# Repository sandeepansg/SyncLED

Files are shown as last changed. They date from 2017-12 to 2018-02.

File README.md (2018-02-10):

<h1 align="center"> SyncLED </h1> <br>
<p align="center">
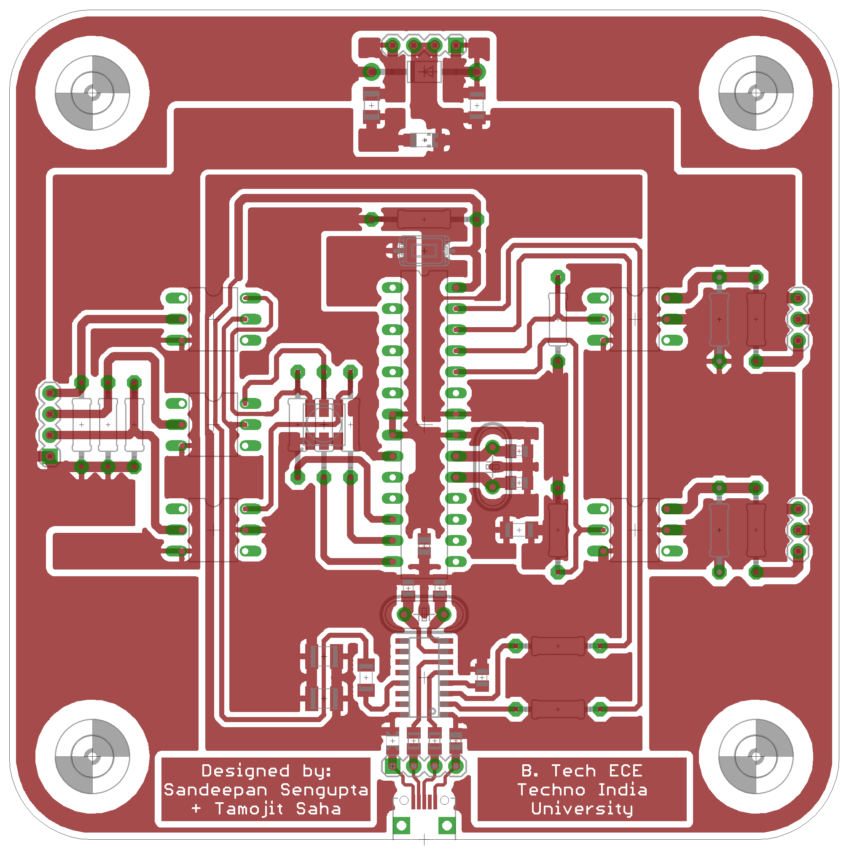
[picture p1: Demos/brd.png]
SyncLED Board Layout

</p>

## Table of Contents

- [Introduction](#introduction)
- [Features](#features)
- [Feedback](#feedback)
- [Contributors](#contributors)
- [License](#license)
- [Acknowledgments](#acknowledgments)

## Introduction






SyncLED is a implementation of a basic secure communication framework to bridge between a host software and a slave LED controller. The host software grabs the bus reported temperature data using [Open Hardware Monitor Library](https://github.com/SandeepanSengupta/SyncLED/blob/master/Sources/Application/Bridge/New/OpenHardwareMonitorLib.dll) and sends it over the usb to the salve embedded led controller using the self-tailored secure communication format.
<p align="center">
  <a href="https://gitpoint.co/">
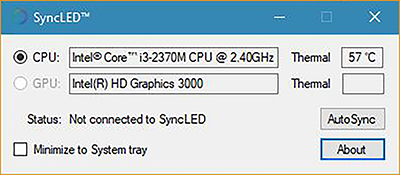
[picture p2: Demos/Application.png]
Windows_App Host Software
    
  </a>
</p>

<p align="center">
  Screenshot of host software.
</p>

## Features
- Real-time temperature monitoring of CPU and GPU
- Temperature dependent LED control
- Independent Host software

## Social
Connect us here:
<br><br>
 <br>
 
<p> 
or <a href ="https://github.com/TamojitSaha/LTC2633/issues/new/">file an issue</a>. Feature requests are always welcome.</p>

## License
Contents of this repository are realeased under [CC-BY-NC-SA 4.0](./LICENSE.md) <br>


## Acknowledgments

Thanks to [Google](https://www.google.com) and various developers for supporting us with a tons of developments... :wink:

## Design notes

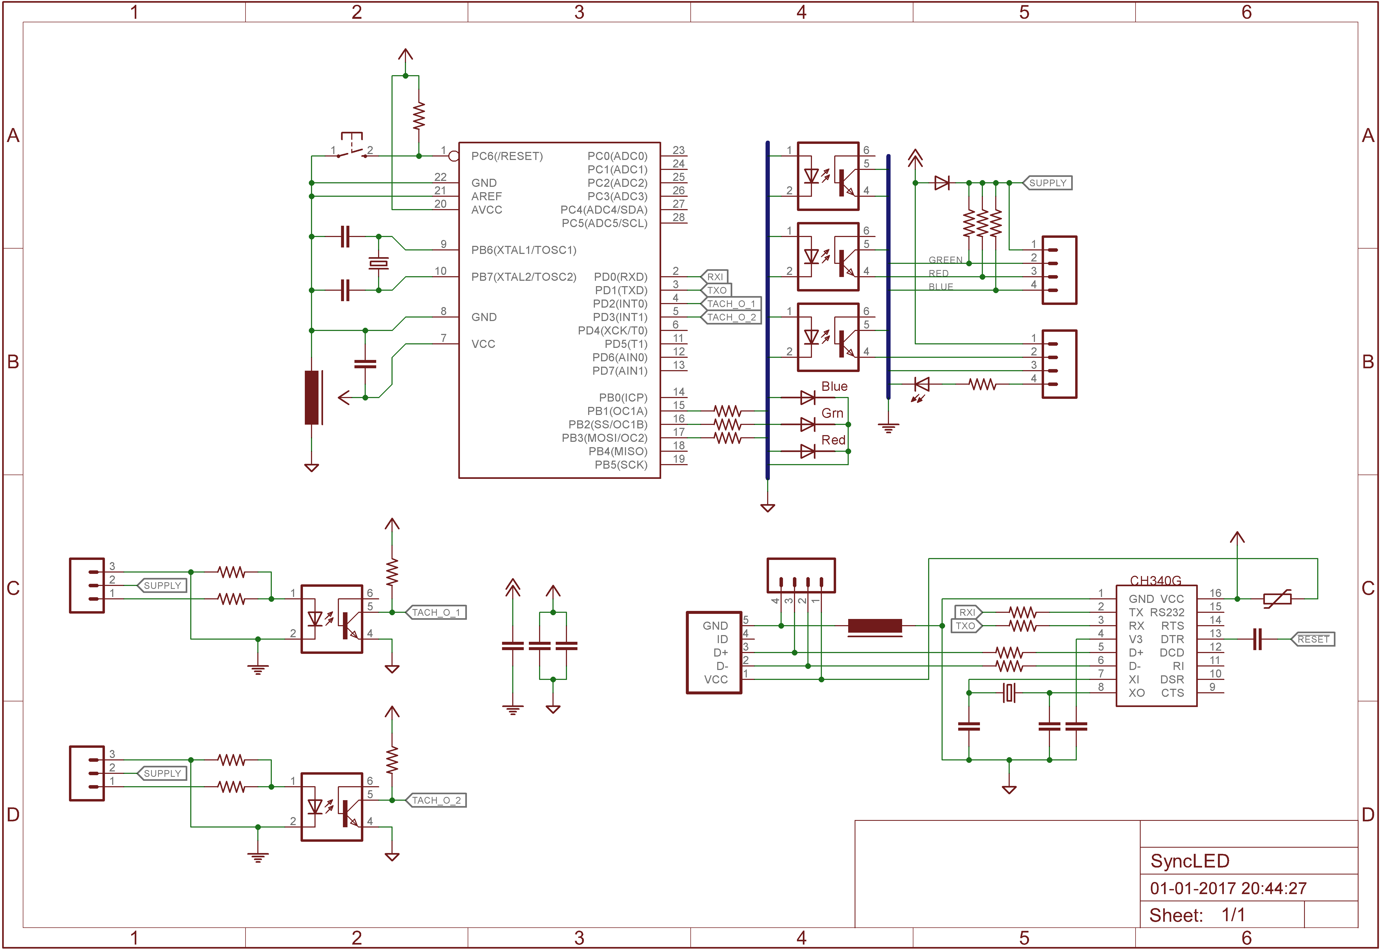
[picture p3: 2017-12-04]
Demos/sch.png

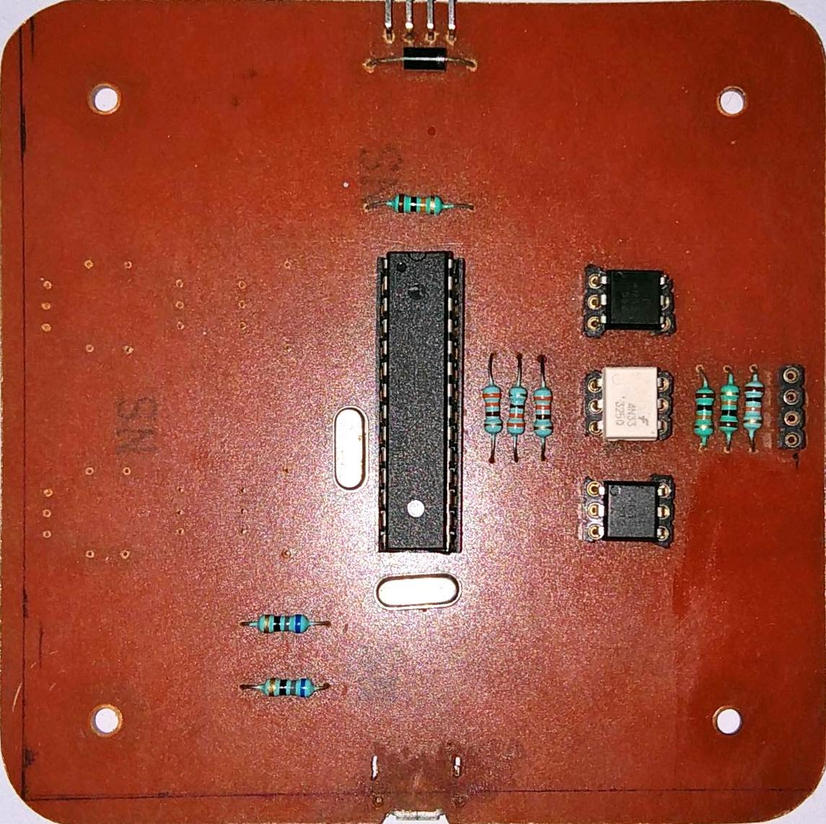
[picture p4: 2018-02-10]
Demos/Device.jpg

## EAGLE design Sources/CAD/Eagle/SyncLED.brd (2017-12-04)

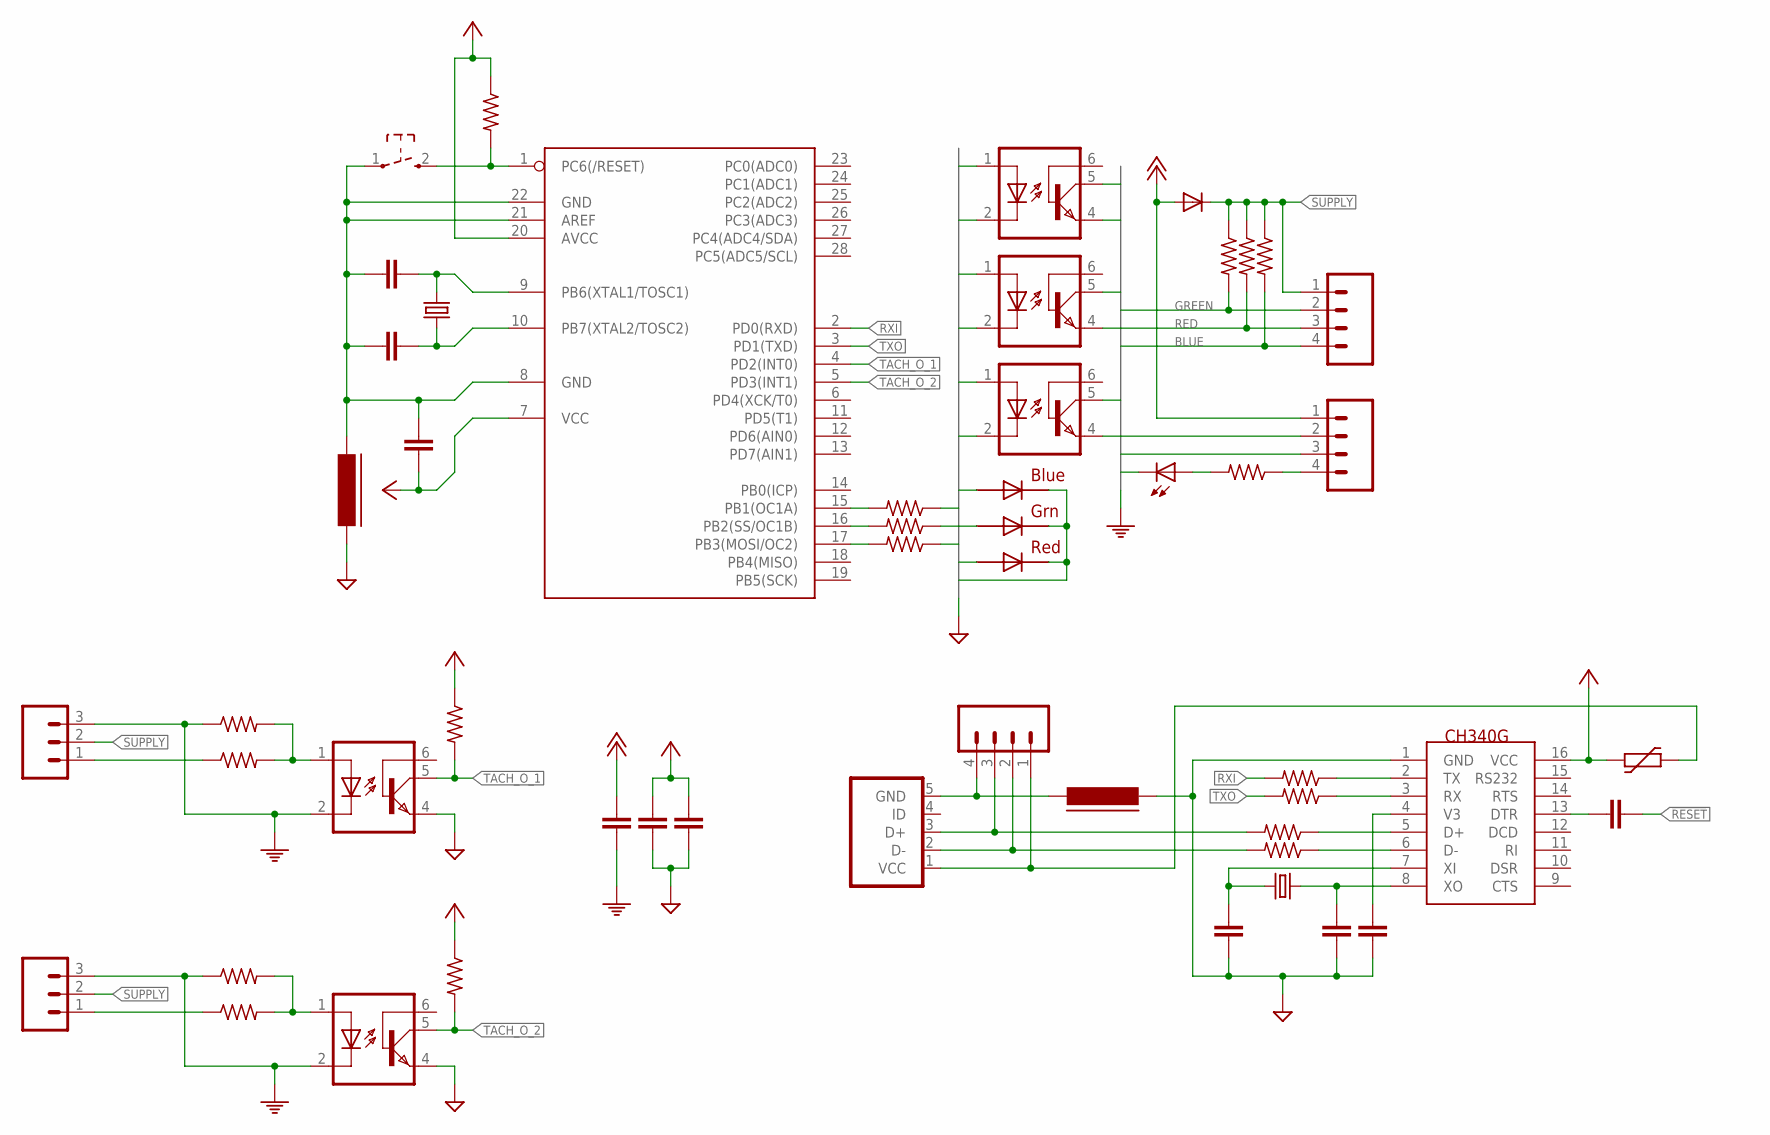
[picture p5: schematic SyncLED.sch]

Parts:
!RES: SMD; SW_TACT_3X6
C1, C2, C3, C4: 22pF; C0805K
CAP_!DTR: 100nF; C1206K
CAP_BYPASS: 22pF; C0805K
CAP_DIGITAL_1, CAP_DIGITAL_2: 1uF; C1210K
CAP_LED: 1uF; C1206K
CAP_MCU: 10uF; C1206K
DIODE_LED: 1N4004; DO41-10
FAN_HEADER_1, FAN_HEADER_2: M03PTH; 1X03
FERRITE_MCU: UGND; FB805
FERRITE_USB: UGND; FB805
INDICATOR: RGBLED5050
LED_OUTPUT: M04PTH; 1X04
MCU: MEGA8-P; DIL28-3
OPTO_BLUE: 4N35; DIL06
OPTO_GREEN: 4N35; DIL06
OPTO_RED: 4N35; DIL06
OPTO_TACH_1, OPTO_TACH_2: 4N35; DIL06
POWER_INDICATOR: LEDCHIPLED_1206; CHIPLED_1206
PPTC: 500mA; PTC0805
RES_BLUE: 10K; 0207/10
RES_B_IN: 100E; 0207/12
RES_D+: 100E; M0805
RES_D-: 100E; M0805
RES_GREEN: 10K; 0207/10
RES_G_IN: 100E; 0207/12
RES_LED: 10K; M1206
RES_PULLUP: 10K; 0207/12
RES_RED: 10K; 0207/10
RES_RX: 100E; 0207/10
RES_R_IN: 100E; 0207/12
RES_TACH_1, RES_TACH_2: 100E; 0207/10
RES_TACH_PULLDOWN_1, RES_TACH_PULLDOWN_2: 1K; 0207/10
RES_TACH_PULLUP_1, RES_TACH_PULLUP_2: 10K; 0207/10
RES_TX: 100E; 0207/10
SMPS_SUPPLY: M04PTH; 1X04
USB2UART: CH340G; SOIC16
USB-RECEPTABLE: USB-Micro; FCI-10103594-0001LF
USB_PORT: M04PTH; 1X04
XTAL_MCU: CRYSTALHC49S; HC49/S
XTAL_USB: CRYSTALHC49S; HC49/S

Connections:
3V: CAP_BYPASS.1, USB2UART.4 (V3)
!DTR: CAP_!DTR.1, USB2UART.13 (DTR)
!RESET: !RES.2 (3), CAP_!DTR.2, MCU.1 (PC6(/RESET)), RES_PULLUP.2
+5V: CAP_DIGITAL_1.1, CAP_DIGITAL_2.1, CAP_MCU.1, MCU.7 (VCC), MCU.20 (AVCC), PPTC.1, RES_PULLUP.1, RES_TACH_PULLUP_1.1, RES_TACH_PULLUP_2.1, USB2UART.16 (VCC)
+12V: CAP_LED.1, DIODE_LED.A, SMPS_SUPPLY.1
BLUE: LED_OUTPUT.4, OPTO_BLUE.5 (COL), RES_BLUE.2
B_IN: MCU.17 (PB3(MOSI/OC2)), RES_B_IN.2
B_OUT: INDICATOR.3 (BLUE_A), OPTO_BLUE.1 (A), RES_B_IN.1
DGND: C1.2, C2.2, CAP_BYPASS.2, CAP_DIGITAL_1.2, CAP_DIGITAL_2.2, FERRITE_MCU.1, FERRITE_USB.2, INDICATOR.4 (BLUE_C), INDICATOR.5 (RED_C), INDICATOR.6 (GREEN_C), OPTO_BLUE.2 (C), OPTO_GREEN.2 (C), OPTO_RED.2 (C), OPTO_TACH_1.4 (EMI), OPTO_TACH_2.4 (EMI), USB2UART.1 (GND)
DI_I: RES_D+.2, USB-RECEPTABLE.3 (D+), USB_PORT.3
DI_O: RES_D-.2, USB-RECEPTABLE.2 (D-), USB_PORT.2
DO_N: RES_D-.1, USB2UART.6 (D-)
DO_P: RES_D+.1, USB2UART.5 (D+)
GREEN: LED_OUTPUT.2, OPTO_GREEN.5 (COL), RES_RED.2
GROUND: CAP_LED.2, FAN_HEADER_1.3, FAN_HEADER_2.3, OPTO_BLUE.4 (EMI), OPTO_GREEN.4 (EMI), OPTO_RED.4 (EMI), OPTO_TACH_1.2 (C), OPTO_TACH_2.2 (C), POWER_INDICATOR.C, RES_TACH_PULLDOWN_1.1, RES_TACH_PULLDOWN_2.1, SMPS_SUPPLY.2, SMPS_SUPPLY.3
G_IN: MCU.16 (PB2(SS/OC1B)), RES_G_IN.2
G_OUT: INDICATOR.1 (GREEN_A), OPTO_GREEN.1 (A), RES_G_IN.1
LED_SUPPLY: POWER_INDICATOR.A, RES_LED.2
MCU_GND: !RES.1, C3.1, C4.1, CAP_MCU.2, FERRITE_MCU.2, MCU.8 (GND), MCU.21 (AREF), MCU.22 (GND)
MCU_XI: C3.2, MCU.9 (PB6(XTAL1/TOSC1)), XTAL_MCU.2
MCU_XO: C4.2, MCU.10 (PB7(XTAL2/TOSC2)), XTAL_MCU.1
RED: LED_OUTPUT.3, OPTO_RED.5 (COL), RES_GREEN.2
RXI: MCU.2 (PD0(RXD)), RES_TX.2
RXO: RES_RX.1, USB2UART.3 (RX)
R_IN: MCU.15 (PB1(OC1A)), RES_R_IN.2
R_OUT: INDICATOR.2 (RED_A), OPTO_RED.1 (A), RES_R_IN.1
SUPPLY: DIODE_LED.C, FAN_HEADER_1.2, FAN_HEADER_2.2, LED_OUTPUT.1, RES_BLUE.1, RES_GREEN.1, RES_RED.1
SUPPLY_5V: RES_LED.1, SMPS_SUPPLY.4
TACH_IN_1: FAN_HEADER_1.1, RES_TACH_1.1
TACH_IN_2: FAN_HEADER_2.1, RES_TACH_2.1
TACH_OPTO_1: OPTO_TACH_1.1 (A), RES_TACH_1.2, RES_TACH_PULLDOWN_1.2
TACH_OPTO_2: OPTO_TACH_2.1 (A), RES_TACH_2.2, RES_TACH_PULLDOWN_2.2
TACH_O_1: MCU.4 (PD2(INT0)), OPTO_TACH_1.5 (COL), RES_TACH_PULLUP_1.2
TACH_O_2: MCU.5 (PD3(INT1)), OPTO_TACH_2.5 (COL), RES_TACH_PULLUP_2.2
TXI: RES_TX.1, USB2UART.2 (TX)
TXO: MCU.3 (PD1(TXD)), RES_RX.2
USB_GND: FERRITE_USB.1, USB-RECEPTABLE.5 (GND), USB_PORT.4
USB_XI: C2.1, USB2UART.7 (XI), XTAL_USB.1
USB_XO: C1.1, USB2UART.8 (XO), XTAL_USB.2
VUSB: PPTC.2, USB-RECEPTABLE.1 (VCC), USB_PORT.1

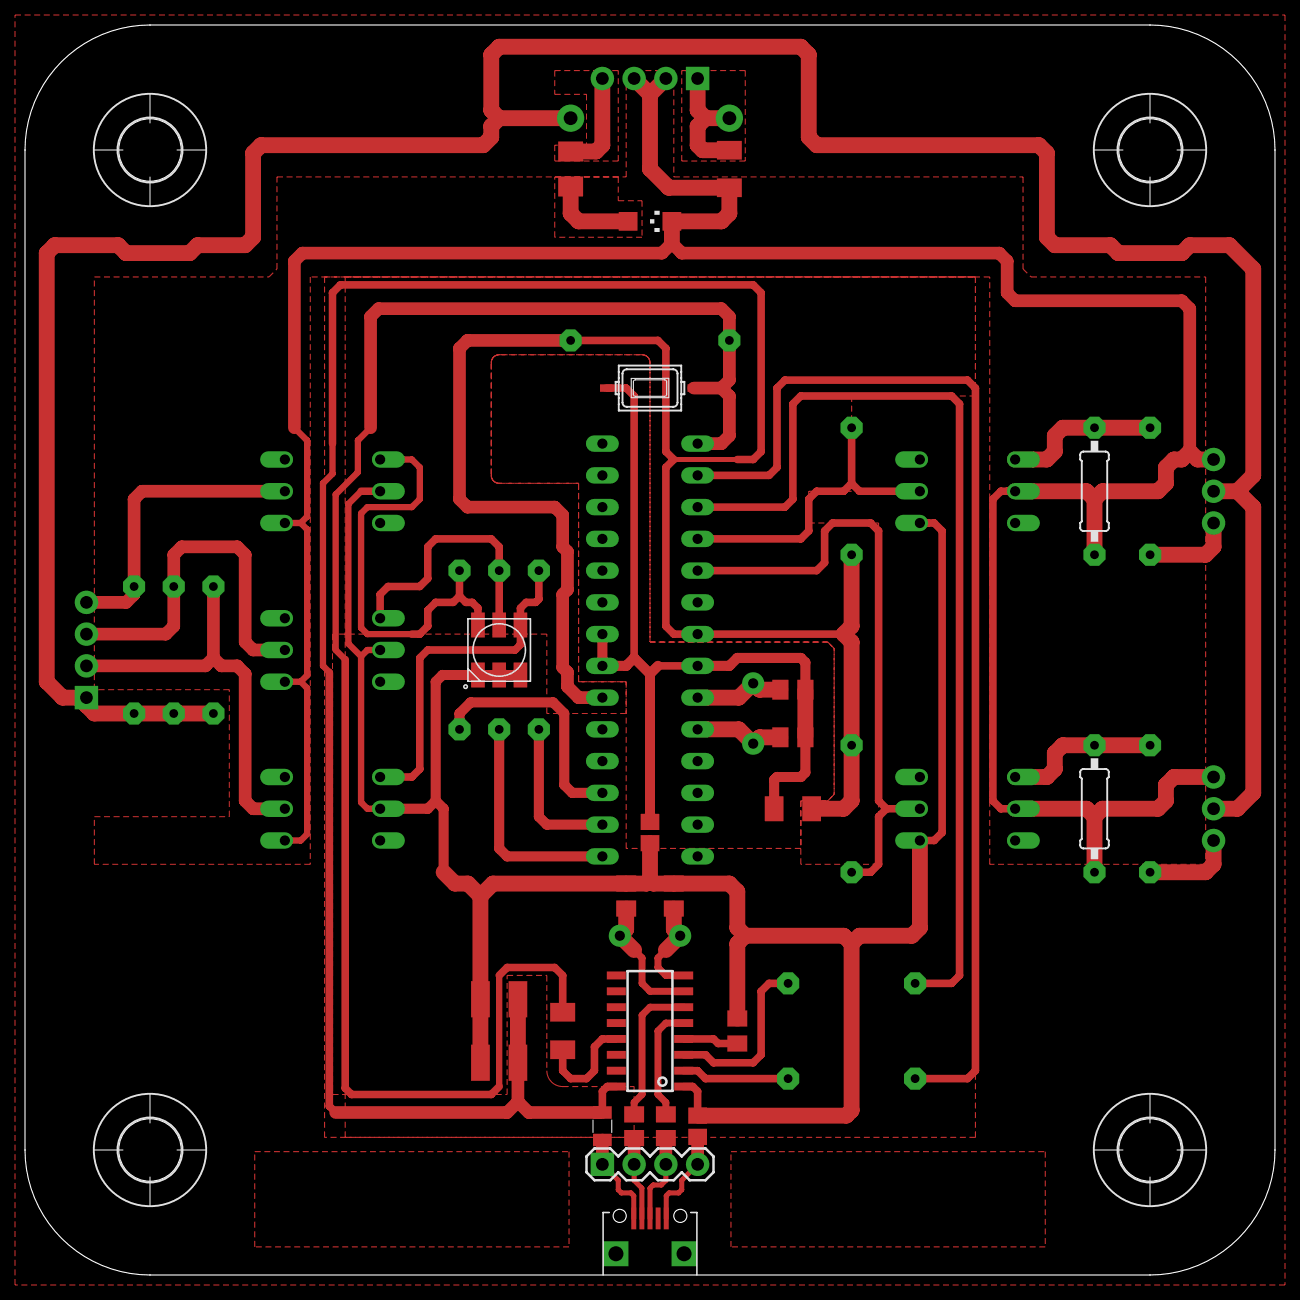
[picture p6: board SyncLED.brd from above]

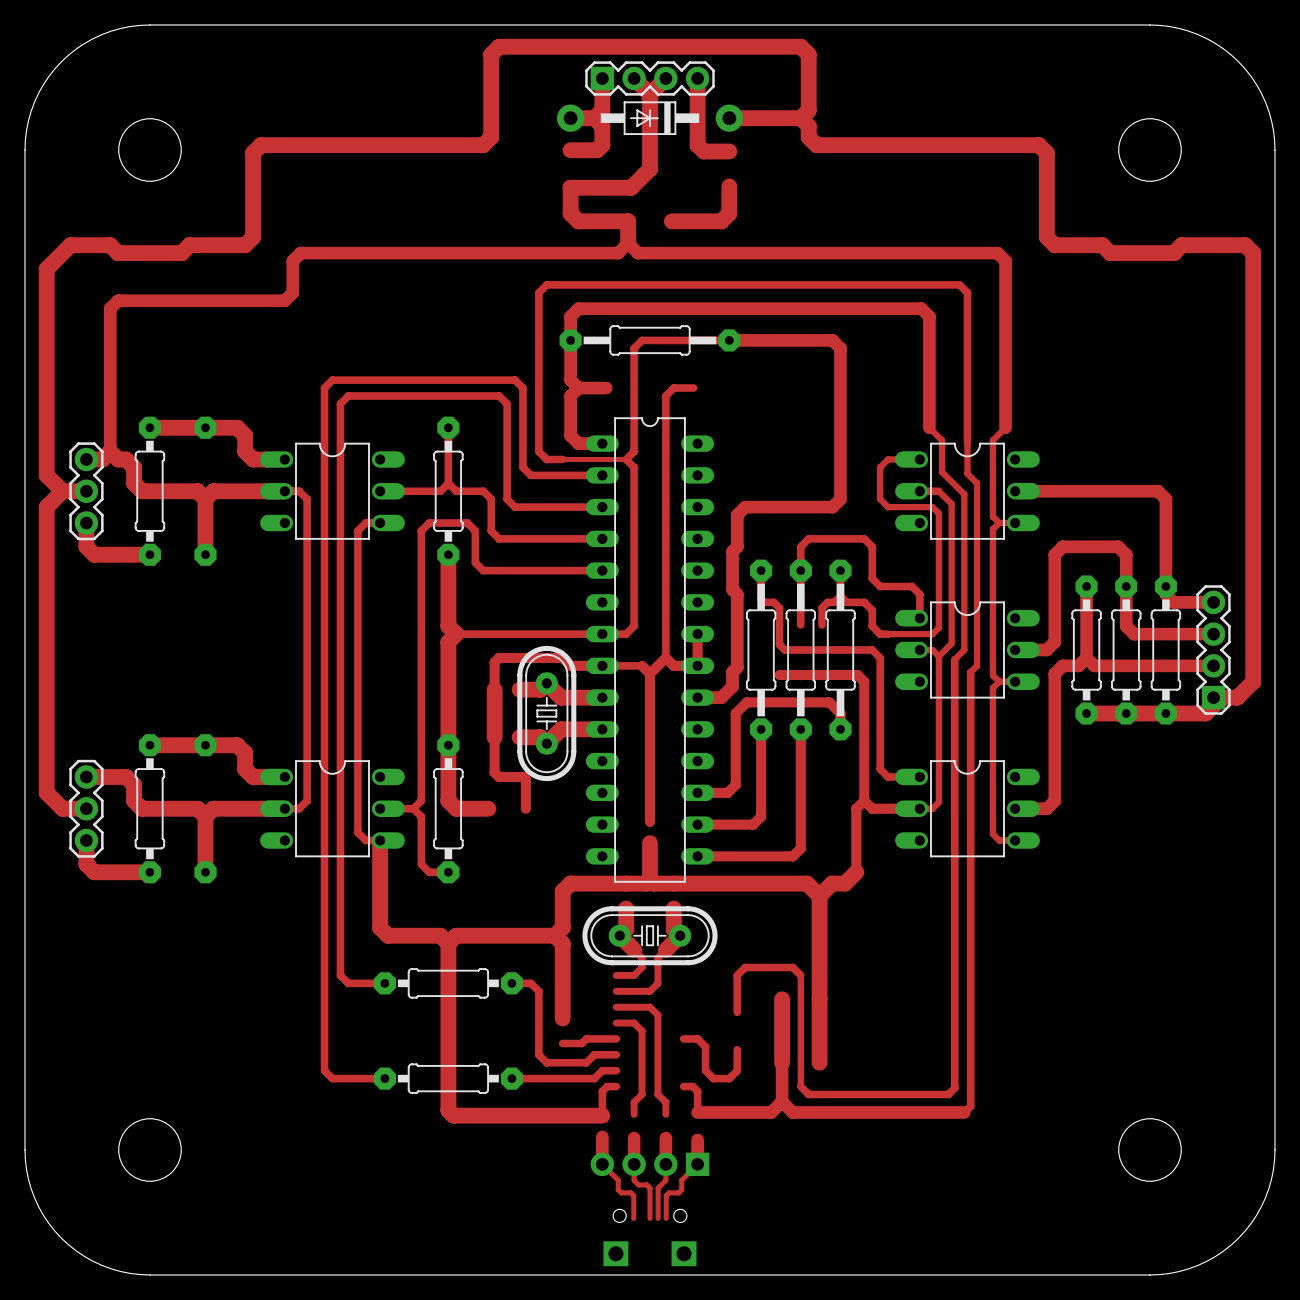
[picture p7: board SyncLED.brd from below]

Board: 2 copper layers, 100.0 x 100.0 mm, 54 parts (26 on the bottom side), 40 nets.

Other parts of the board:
U$1, U$2, U$3, U$5: 5,0

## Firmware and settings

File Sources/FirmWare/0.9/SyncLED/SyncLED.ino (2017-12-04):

/*
  Infineo Communication framework for SyncLED™ (Version 0.9)
  Author(s): Sandeepan Sengupta, Tamojit Saha

  Frame format:

  Inputs are 8 charectors in an UART stream
  Charector 1 is Identifier
  Charector 2~7 are Payload in HEX charectors
  Charector 8 is Termination Indicator

  Registered identifier(s): '~' , '!' , '@' , '#' and '*'
  Registered termination indicator(s): ';'

  '~' is identified as shake back code
  '!' is identified as override request identification code
  '@' is identified as random response identification code (receive)
  '@' is identified as random referance identification code (send)
  '#' is identified as RGB data identification code
  '*' is identified as handshake request identification code

  RGB payload is 6 charectors HEX in 2+2+2 = 6 format (#000000; to #ffffff;)

  Accepted input formats are
  (Single frame)
  eg. *abcdef;
      ~9EF85F;
      @1C8039;
      #ffffff;
  etc...

  (Multiple frames without seperation)
  eg. *63962D;~58F5C;
  @0397DD;#64F5ED;
  etc...

  Test String: *63962D;~58F5C;@300000;#ff0000;@300000;#00ff00;@300000;#0000ff;
  Override Command is !2DFA1067; [ 0771362919 or higher sumDigits() == 9 ]
  @300000;#ff0000;@300000;#00ff04;@300000;#0000ff;!2DFA1067;

  Copyright (c) 2013-2018, IObitZ (https://www.iobitz.com)
*/

#include <avr/interrupt.h>
#include <avr/power.h>
#include <avr/sleep.h>
#include <avr/wdt.h>

#define termChar ';'

#define _idleRecovery_  60000   //MilliSeconds
#define idleTime        10000   //MilliSeconds
#define delayValue      2500    //MicroSeconds
#define pwm_res         8
#define _delay_

#define _return_
//#define _idleLock_    //Disable RGB at the event of inactive blackOut
#define _powerSaver_  //Disable for older AVR (eg. ATmega8)

//#define _initDebug_
//#define _debug_
//#define _blackoutEvent_
//#define _intruderDetect_
//#define _colorDebug_
//#define _fadeDebug_
//#define _TimeStamp_

bool      intruderFlag  = LOW;
boolean   flip          = false;
boolean   rgbEnabled    = false;
boolean   validEvent    = false;
boolean   blackoutState = false;
boolean   sampleWaiting = false;

uint8_t   RGB_value[3]  = {};
uint8_t   RGB_pin[3]    = {9, 10, 11};

uint8_t   index         = NULL;
uint8_t   unitSum       = NULL;
uint8_t   autoValue     = NULL;
uint8_t   current_bit   = NULL;

uint16_t  counter       = NULL;

uint32_t  meta          = NULL;
uint32_t  seed          = NULL;
uint32_t  sample        = NULL;
uint32_t  response      = NULL;
uint32_t  challenge     = NULL;
uint32_t  idleColor     = NULL;
uint32_t  eventStamp    = NULL;

void setup()
{
  wdt_reset();
  wdtSetup();

  Serial.begin(115200);
  {
    while (!Serial);
  }
  for (uint8_t i = 0; i < 3; i++)
  {
    pinMode(RGB_pin[i], OUTPUT);
  }

#ifdef _debug_
  Serial.println("Infineo Communication framework for SyncLED™ v0.9\nAuthor(s): Sandeepan Sengupta, Tamojit Saha\nCopyright (c) 2015-2017, IObitZ (https://www.iobitz.com)\n\n");
#endif

}

void loop()
{
  if (sampleWaiting)
  {
    sampleWaiting = false;

    seed = rotl(seed, 1); // Spread randomness around
    seed ^= sample; // XOR preserves randomness

    current_bit++;
    if (current_bit > 31)
    {
      current_bit = NULL;
    }
  }

  uint8_t RGB_Old_Val[3] = {};
  for (uint8_t i = 0; i < 3; i++)
  {
    RGB_Old_Val[i] = RGB_value[i];
  }

  if (validEvent == true && intruderFlag == LOW)
  {
    uint32_t lapseTime = millis() - eventStamp;
    if (lapseTime >= idleTime)
    {
      eventStamp = millis();
      for (uint8_t i = NULL; i < 3; i++)
      {
        if (RGB_value[i] != NULL)
        {
          RGB_value[i]  = NULL;
        }
      }

      if (rgbEnabled == true)
      {

#ifdef  _blackoutEvent_
        Serial.print("Inactivity in milliseconds:\t");
        Serial.println(lapseTime);
        Serial.print("Blackout triggered at:\t");
        Serial.print(millis());
        Serial.println("th milliseconds");
#endif

#ifdef _idleLock_
        rgbEnabled  = false;
#endif

        validEvent  = false;

#ifdef _return_
        WriteStringLn("696e616374697665"); //inactive
#endif

        blackoutState = blackOut(RGB_pin, RGB_Old_Val, delayValue);

#ifdef _return_
        WriteStringLn("426c61636b4f7574\n");  //BlackOut
#endif


      }

      if (blackoutState == true)
      {

#ifdef _powerSaver_
        powerSaver();
#endif

      }
    }
  }

  uint32_t  lockdownTimer = millis();
  if (intruderFlag == HIGH)
  {
    if (lockdownTimer == NULL)  //Timer overflow
    {
      intruderFlag = LOW;

#ifdef _intruderDetect_
      Serial.print("Lockdown disengaged");
#endif

      wdt_enable(WDTO_15MS);    //Schedule a !RESET after 15ms
      block();                  //Block program execution and wait for reset
    }
  }

  if (index > 3)
  {
    index = NULL;
  }

#ifdef _initDebug_
  Serial.print(index);
  Serial.print("\t");
  Serial.print(flip);
  Serial.print("\t");
  Serial.print(RGB_value[0]);
  Serial.print("\t");
  Serial.print(RGB_value[1]);
  Serial.print("\t");
  Serial.print(RGB_value[2]);
  Serial.print("\n");
#endif

  if (blackoutState == false && rgbEnabled == false)
  {
    for (uint8_t i = NULL; i < 3; i++)
    {
      analogWrite(RGB_pin[i], RGB_value[i]);
    }
    delayMicroseconds(delayValue);
    RGB_value[index] = counter;
    if (counter > (pow(2, pwm_res) - 1))
    {
      flip = !flip;
      index++;
    }
    if (!flip)
    {
      counter++;
    }
    else
    {
      counter--;
    }
    if (counter == NULL)
    {
      flip = !flip;
    }
    if (index == 3)
    {
      counter = pow(2, pwm_res); //Artificially creating the exit condition
      flip = false;
    }
  }

#ifdef _idleRecovery_
  if (blackoutState == true && intruderFlag == LOW && ((millis() - eventStamp) >= _idleRecovery_))
  {
    wdt_enable(WDTO_15MS);    //Schedule a !RESET after 15ms
    block();                  //Block program execution and wait for reset
  }
#endif

  Serial.flush();
  while (Serial.available() > NULL)
  {
    String  serialData  = Serial.readStringUntil(termChar);
    serialData.trim();
    char id = serialData.charAt(NULL);
    {
      switch (id)
      {
        case '~':
          if (intruderFlag == HIGH)
          {

#ifdef _intruderDetect_
            Serial.print("Code injection detected.\nSystem lockdown triggered !!!\nTry after:\t");
            Serial.print(- lockdownTimer);
            Serial.println(" MilliSeconds\n");
#endif

#ifdef _return_
            WriteStringLn("4c6f636b446f776e"); //LockDown
#endif

            Serial.flush();
          }
          else  if  (intruderFlag == LOW)
          {
            validEvent = true;
          }
          break;

        case '!':
          if (intruderFlag == HIGH)
          {
            validEvent = true;
          }
          else  if  (intruderFlag == LOW)
          {
            validEvent = false;
          }
          break;

        case '@':
          if (intruderFlag == HIGH)
          {
#ifdef _intruderDetect_
            Serial.print("Code injection detected.\nSystem lockdown triggered !!!\nTry after:\t");
            Serial.print(- lockdownTimer);
            Serial.println(" MilliSeconds\n");
#endif

#ifdef _return_
            WriteStringLn("4c6f636b446f776e"); //LockDown
#endif

            Serial.flush();
          }
          else  if  (intruderFlag == LOW)
          {
            validEvent = true;
          }
          break;

        case '#':
          if (intruderFlag == HIGH)
          {

#ifdef _intruderDetect_
            Serial.print("Code injection detected.\nSystem lockdown triggered !!!\nTry after:\t");
            Serial.print(- lockdownTimer);
            Serial.println(" MilliSeconds\n");
#endif

#ifdef _return_
            WriteStringLn("4c6f636b446f776e"); //LockDown
#endif
            Serial.flush();
          }
          else  if  (intruderFlag == LOW)
          {
            validEvent = true;
          }
          break;

        case '*':
          if (intruderFlag == HIGH)
          {

#ifdef _intruderDetect_
            Serial.print("Code injection detected.\nSystem lockdown triggered !!!\nTry after:\t");
            Serial.print(- lockdownTimer);
            Serial.println(" MilliSeconds\n");
#endif

#ifdef _return_
            WriteStringLn("4c6f636b446f776e"); //LockDown
#endif

            Serial.flush();
          }
          else  if  (intruderFlag == LOW)
          {
            validEvent = true;
          }
          break;

        default:
          exit(NULL);
          break;
      }

      if (validEvent == true)
      {
        Serial.flush();
        eventStamp = millis();

        serialData.remove(NULL, String(id).length());
        uint32_t  code = (uint32_t)strtol( &serialData[NULL], NULL, HEX);

#ifdef _debug_
        Serial.print("Entered string data is\t\t:\t'");
        Serial.print(id);
        Serial.print(serialData);
        Serial.print(termChar);
        Serial.println("'");

        Serial.print("Rectified code (in HEX) is\t:\t");
        Serial.print(code, HEX);
        Serial.println("\n");

        Serial.print("Configuration code in DEC\t:\t");
        Serial.println(code, DEC);
        Serial.print("Configuration code in BIN\t:\t");
        Serial.println(code, BIN);
        Serial.print("\n");
#endif

        boolean verifier = false;
        switch (id)
        {
          case '~':
            if (unitSum == sumDigits(code) && code != response && code != challenge)
            {
              syncIndicate(RGB_pin, RGB_value, delayValue);
              for (uint8_t i = NULL; i < 3; i++)
              {
                RGB_Old_Val[i] = RGB_value[i];
              }
              rgbEnabled = true;
              randomSeed(randRes(code));
              WriteStringLn("@" + String(random(), HEX) + String(termChar));

#ifdef _debug_
              Serial.println("RGB Enabled");
              Serial.print("\n\0\r");
#endif

            }
            else
            {
              validEvent    = false;
              unitSum       = NULL;
              rgbEnabled    = false;
              intruderFlag  = HIGH;
              if (blackoutState == false)
              {

#ifdef _return_
                WriteStringLn("696e747275646572"); //intruder
#endif

                blackoutState = blackOut(RGB_pin, RGB_Old_Val, delayValue);

#ifdef _return_
                WriteStringLn("426c61636b4f7574\n");  //BlackOut
#endif

              }
            }
            break;

          case '!':
            if ( code >= 771362919 && sumDigits(code) == sumDigits(9192631770) )
            {

#ifdef _debug_
              Serial.println("Forced RESET");
              Serial.print("\n\0\r");
#endif

              WriteStringLn("6f76657272696465"); //override

              wdt_enable(WDTO_15MS);    //Schedule a !RESET after 15ms
              block();                  //Block program execution and wait for reset
            }
            break;

          case '@':
            meta = code;
            break;

          case '#':
            if (meta != code || code == NULL || code == 0xFFFFFF)
            {
              verifier = true;
            }
            if (sumDigits(meta) == sumDigits(code) && verifier == true)
            {
              if (rgbEnabled == true)
              {
                RGB_value[0]  = code >> 16;
                RGB_value[1]  = code >> 8 & 0xFF;
                RGB_value[2]  = code & 0xFF;

                fadeRGB(RGB_value, RGB_Old_Val, delayValue);

                WriteStringLn("@" + String(randRes(meta), HEX) + String(termChar));
              }
            }
            else
            {
              validEvent    = false;
              intruderFlag  = HIGH;

#ifdef _return_
              WriteStringLn("696e747275646572"); //intruder
#endif

              if (blackoutState == false)
              {
                blackoutState = blackOut(RGB_pin, RGB_Old_Val, delayValue);

#ifdef _return_
                WriteStringLn("426c61636b4f7574\n");  //BlackOut
#endif

              }
            }
            break;

          case '*':
            challenge = code;
            response  = randRes(code);
            unitSum   = sumDigits(code);
            WriteStringLn("~" + String(response, HEX) + String(termChar));
            break;

          default:
            exit(NULL);
            break;
        }

#ifdef _debug_
        if (RGB_value[0] == NULL && RGB_value[1] == NULL && RGB_value[2] == NULL)
        {
          Serial.println("RGB Disabled");
          Serial.print("\n\0\r");
        }
#endif

      }

#ifdef _blackoutEvent_
      if (validEvent == true)
      {
        Serial.print("Valid Event for\t");
        Serial.print(id);
        Serial.print("\thappened at:\t");
        Serial.print(eventStamp);                   //Serial buffer frezes here sometimes
        Serial.println("th MilliSeconds\n");
      }
#endif

    }
  }
}



/*User derived Functions*/

void block()
{
  for (;;)
  {
    ;
  }
}

void syncIndicate(uint8_t pinRGB[3], uint8_t RGB_PWM[3], uint32_t Interval)
{
  for (uint8_t i = NULL; i < 3; i++)
  {
    while (RGB_PWM[i] != (pow(2, pwm_res) - 1))
    {
      RGB_PWM[i]++;

#ifdef _colorDebug_
      for (uint8_t i = NULL; i < 3; i++)
      {
        Serial.flush();
        Serial.print(i);
        Serial.print(":\t");
        Serial.println(RGB_PWM[i]);
      }
#endif

      analogWrite(pinRGB[i], RGB_PWM[i]);

#ifdef _delay_
      delayMicroseconds(Interval);
#endif

    }
  }
}

boolean blackOut(uint8_t pinRGB[3], uint8_t RGB_PWM[3], uint32_t Interval)
{
  for (uint8_t i = NULL; i < 3; i++)
  {
    while (RGB_PWM[i] != NULL)
    {
      RGB_PWM[i]--;

#ifdef _colorDebug_
      for (uint8_t i = NULL; i < 3; i++)
      {
        Serial.flush();
        Serial.print(i);
        Serial.print(":\t");
        Serial.println(RGB_PWM[i]);
      }
#endif

      analogWrite(pinRGB[i], RGB_PWM[i]);

#ifdef _delay_
      delayMicroseconds(Interval);
#endif

    }
  }
  return (true);
}

uint8_t sumDigits(uint64_t num)
{
  uint8_t sumOne = NULL;
  while (num > NULL)
  {
    sumOne += num % 10;
    num /= 10;
  }
  if (sumOne > 9)
  {
    sumOne = sumDigits(sumOne);
  }
  return sumOne;
}

uint32_t randRes(uint32_t information)
{
  boolean match;
  while (match == false)
  {
    randomSeed(micros() + seed);
    uint32_t response = random(NULL, pow(2, sizeof(uint32_t) * String(information, HEX).length()));
    if (information != response && sumDigits(information) == sumDigits(response))
    {
      match = true;
      return response;
    }
  }
}

void WriteString(String stringData)
{
  for (uint8_t i = NULL; i < stringData.length(); i++)
  {
    Serial.write(stringData[i]);
  }
}

void WriteStringLn(String stringData)
{
  for (uint8_t i = NULL; i < stringData.length(); i++)
  {
    Serial.write(stringData[i]);
  }
  Serial.write("\n\0\r");
}

void fadeRGB (uint8_t RGB_currVal[3], uint8_t RGB_preVal[3], uint32_t Interval)
{

#ifdef _TimeStamp_
  uint32_t startPoint = millis();
#endif

  for (uint8_t i = NULL; i < 3; i++)
  {
    RGB_currVal[i] = RGB_value[i];
  }

  for (uint8_t i = NULL; i < 3; i++)
  {
    if (RGB_preVal[i] > RGB_currVal[i])
    {
      while (RGB_preVal[i] > RGB_currVal[i])
      {
        {
          RGB_preVal[i]--;
          analogWrite(RGB_pin[i], RGB_preVal[i]);

#ifdef _fadeDebug_
          Serial.println("Decrementing...");
          Serial.print("RED is\t\t\t\t:\t");
          Serial.println(RGB_preVal[0]);
          Serial.print("GREEN is\t\t\t:\t");
          Serial.println(RGB_preVal[1]);
          Serial.print("BLUE is\t\t\t\t:\t");
          Serial.println(RGB_preVal[2]);
          Serial.print("RGB color value set is\t\t:\t(");
          Serial.print(RGB_preVal[0], HEX);
          Serial.print(",");
          Serial.print(RGB_preVal[1], HEX);
          Serial.print(",");
          Serial.print(RGB_preVal[2], HEX);
          Serial.println(")");
          Serial.print("\n");
#endif

        }

#ifdef  _delay_
        delayMicroseconds(Interval);
#endif

      }
    }
    else if (RGB_preVal[i] < RGB_currVal[i])
    {
      while (RGB_preVal[i] < RGB_currVal[i])
      {
        {
          RGB_preVal[i]++;
          analogWrite(RGB_pin[i], RGB_preVal[i]);

#ifdef _fadeDebug_
          Serial.println("Incrementing...");
          Serial.print("RED is\t\t\t\t:\t");
          Serial.println(RGB_preVal[0]);
          Serial.print("GREEN is\t\t\t:\t");
          Serial.println(RGB_preVal[1]);
          Serial.print("BLUE is\t\t\t\t:\t");
          Serial.println(RGB_preVal[2]);
          Serial.print("RGB color value set is\t\t:\t(");
          Serial.print(RGB_preVal[0], HEX);
          Serial.print(",");
          Serial.print(RGB_preVal[1], HEX);
          Serial.print(",");
          Serial.print(RGB_preVal[2], HEX);
          Serial.println(")");
          Serial.print("\n");
#endif

#ifdef  _delay_
          delayMicroseconds(Interval);
#endif

        }
      }
    }
    else
    {
      {
        analogWrite(RGB_pin[i], RGB_preVal[i]);

#ifdef _fadeDebug_
        Serial.println("Color Refresh");
        Serial.print("RED is\t\t\t\t:\t");
        Serial.println(RGB_preVal[0]);
        Serial.print("GREEN is\t\t\t:\t");
        Serial.println(RGB_preVal[1]);
        Serial.print("BLUE is\t\t\t\t:\t");
        Serial.println(RGB_preVal[2]);
        Serial.print("RGB color value set is\t\t:\t(");
        Serial.print(RGB_preVal[0], HEX);
        Serial.print(",");
        Serial.print(RGB_preVal[1], HEX);
        Serial.print(",");
        Serial.print(RGB_preVal[2], HEX);
        Serial.println(")");
        Serial.print("\n");
#endif

#ifdef  _delay_
        delayMicroseconds(Interval);
#endif

      }
    }
  }

#ifdef _TimeStamp_
  Serial.print("RGB transition time in milliseconds:\t");
  Serial.println(millis() - startPoint);
#endif

}

#ifdef _powerSaver_
void powerSaver()
{
  set_sleep_mode(SLEEP_MODE_IDLE);

  sleep_enable();
  power_adc_disable();
  power_spi_disable();
  power_timer0_disable();
  power_timer1_disable();
  power_timer2_disable();
  power_twi_disable();

  sleep_mode();

  sleep_disable();
  power_all_enable();
}
#endif


// Rotate bits to the left
// https://en.wikipedia.org/wiki/Circular_shift#Implementing_circular_shifts
uint32_t rotl(const uint32_t value, uint32_t shift)
{
  if ((shift &= sizeof(value) * 8 - 1) == NULL)
    return value;
  return (value << shift) | (value >> (sizeof(value) * 8 - shift));
}

// Setup of the watchdog timer.
void wdtSetup()
{
  cli();
  MCUSR = NULL;

  /* Start timed sequence */
  WDTCSR |= _BV(WDCE) | _BV(WDE);

  /* Put WDT uint32_to uint32_terrupt mode */
  /* Set shortest prescaler(time-out) value = 2048 cycles (~16 ms) */
  WDTCSR = _BV(WDIE);

  sei();
}

// Watchdog Timer Interrupt Service Routine
ISR(WDT_vect)
{
  sample = TCNT1L; // Ignore higher bits
  sampleWaiting = true;
}

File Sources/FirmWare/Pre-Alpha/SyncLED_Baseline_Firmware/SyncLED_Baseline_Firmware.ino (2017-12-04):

/*
  Communication framework for SyncLED v0.1
  Author(s): Sandeepan Sengupta, Tamojit Saha
  Special thanks to: Sumant Banerjee, B.Tech (Electrical Engineering), West Bengal University of Technology


  Frame format:

  Inputs are 8 charectors in an UART stream
  Charector 1 is Identifier
  Charector 2~7 are Payload in HEX charectors
  Charector 8 is Termination Indicator

  Registered identifier(s): '~' , '#' and '*'
  Registered termination indicator(s): ';'

  '~' is identified as shake back code
  '#' is identified as RGB data
  '*' is identified as information code

  RGB payload (both address and data) is 6 charectors HEX in 2+2+2 = 6 format (#000000; to #ffffff;)

  Configuration payload is converted into 24 charectors BIN from 6 charector HEX
  24 charectors BIN in in 1+8+(5+5+5) = 24 format
  1st bit (BIT_0) used to change LED State
  2nd to 9th bit (BIT_1 ~ BIT_8) is used to produce PWM code for intensity adjustment
  Rest of the bits(all 15 of them in 5+5+5 format) are used to feed shift registers secondary configuration data to drive 5x5x5 LED cube

  Accepted input formats are
  (Single frame)
  *abcdef;
  ~9EF85F;
  @1C8039;
  #ffffff;
  etc...

  (Multiple frames without seperation)
  c
  etc...

  Copyright (c) 2015-2016, Intelectron India (https://www.intelectron.in)
*/

#define termChar ';'

#define _rndRsp_

#define _debug_
//#define _$_

uint8_t RGB_pin[3]    = {9, 10, 11};
uint8_t RGB_value[3]  = {};

uint8_t unitSum       = NULL;
boolean rgbEnabled    = false;

uint32_t  code        = NULL;
uint32_t  meta        = NULL;

#ifdef  _$_
uint32_t  testNum     = NULL;
String    testStr     = "";
#endif

void setup()
{
  Serial.begin(115200);
  {
    while (!Serial);
  }
  for (uint8_t j = 0; j < 3; j++)
  {
    pinMode(RGB_pin[j], OUTPUT);
  }
}

void loop()
{
  Serial.flush();
  while (Serial.available() > 0)
  {
    String  serialData  = Serial.readStringUntil(termChar);
    serialData.trim();
    char id = serialData.charAt(NULL);
    {
      boolean change  = false;
      switch (id)
      {
        case '~':
          change = true;
          break;

        case '@':
          change = true;
          break;

        case '#':
          change = true;
          break;

#ifdef _$_
        case '$':
          change = true;
          break;
#endif

        case '*':
          change = true;
          break;

        default:
          change = false;
          break;
      }

      if (change == true)
      {
        serialData.remove(NULL, String(id).length());
        code = (uint32_t)strtol( &serialData[NULL], NULL, HEX);

#ifdef _debug_
        Serial.print("Entered string data is\t\t:\t'");
        Serial.print(serialData);
        Serial.println("'");

        Serial.print("Rectified code (in HEX) is\t:\t");
        Serial.print(code, HEX);
        Serial.println("\n");

        Serial.print("Configuration code in DEC\t:\t");
        Serial.println(code, DEC);
        Serial.print("Configuration code in BIN\t:\t");
        Serial.println(code, BIN);
        Serial.print("\n");
#endif

        uint32_t rsp = NULL;
        switch (id)
        {
          case '~':
            if (unitSum == sumDigits(code))
            {
              rgbEnabled = true;
            }
            else
            {
              rgbEnabled = false;
              unitSum = NULL;
            }
            break;

          case '@':
            meta = code;
            break;

          case '#':
            if (sumDigits(meta) == sumDigits(code) && rgbEnabled == true)
            {
#ifdef _debug_
              Serial.println("RGB Enabled");
              Serial.print("\n");
#endif
              RGB_value[0]  = code >> 16;
              RGB_value[1]  = code >> 8 & 0xFF;
              RGB_value[2]  = code & 0xFF;
            }
#ifdef _debug_
            Serial.print("RED is\t\t\t\t:\t");
            Serial.println(RGB_value[0]);
            Serial.print("GREEN is\t\t\t:\t");
            Serial.println(RGB_value[1]);
            Serial.print("BLUE is\t\t\t\t:\t");
            Serial.println(RGB_value[2]);
            Serial.print("RGB color value set is\t\t:\t(");
            Serial.print(RGB_value[0], HEX);
            Serial.print(",");
            Serial.print(RGB_value[1], HEX);
            Serial.print(",");
            Serial.print(RGB_value[2], HEX);
            Serial.println(")");
            Serial.print("\n");
#endif
            for (uint8_t j = NULL; j < 3; j++)
            {
              analogWrite(RGB_pin[j], RGB_value[j]);
            }
            break;

#ifdef _$_
          case '$':
            Serial.print(sumDigits(code));
            Serial.print("\tis the sumDigits(code) for the original code\t0x");
            Serial.println(code, HEX);
            testNum = randRes(code);
            Serial.print(sumDigits(testNum));
            Serial.print("\tis the sumDigits(code) for the randResp(code)\t0x");
            Serial.println(testNum, HEX);
            testStr = randRspStr(code);
            Serial.print("\tis the sumDigits(code) for the randRspStr(code)\t0x");
            Serial.println(testStr);
            Serial.print("\n");
            break;
#endif

          case '*':
#ifdef _rndRsp_
            unitSum = sumDigits(code);
            rsp = randRes(code);
#endif
#ifndef _rndRsp_
            rsp = sumDigits(code);
            unitSum = rsp;
#endif
            writeString("~" + String(rsp, HEX) + ";");
            Serial.write("\n\r\0");
            break;

          default:
            exit(NULL);
            break;
        }
      }
    }
  }
}


/*User derived Functions*/

uint8_t sumDigits(uint32_t num)
{
  uint8_t sumOne = 0;
  while (num > 0)
  {
    sumOne += num % 10;
    num /= 10;
  }
  if (sumOne > 9)
  {
    sumOne = sumDigits(sumOne);
  }
  return sumOne;
}

uint32_t randRes(uint32_t information)
{
  boolean match;
  while (match == false)
  {
    uint32_t response = random(NULL, pow(2, sizeof(uint32_t) * String(information, HEX).length()));
    if (information != response && sumDigits(information) == sumDigits(response))
    {
      match = true;
      return response;
    }
  }
}

#ifdef _$_
String randRspStr(uint32_t information)
{
  boolean match;
  while (match == false)
  {
    uint32_t response = random(NULL, pow(2, sizeof(uint32_t) * String(information, HEX).length()));
    if (information != response && sumDigits(information) == sumDigits(response))
    {
#ifdef _$_
      Serial.print(sumDigits(response));
#endif
      if (String(information, HEX).length() == String(response, HEX).length())
      {
        match = true;
        return String(response, HEX);
      }
      else
      {
        String rspStr = String(response, HEX);
        while (rspStr.length() < String(information, HEX).length())
        {
          rspStr = "0" + rspStr;
        }
        return rspStr;
      }
    }
  }
}
#endif
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

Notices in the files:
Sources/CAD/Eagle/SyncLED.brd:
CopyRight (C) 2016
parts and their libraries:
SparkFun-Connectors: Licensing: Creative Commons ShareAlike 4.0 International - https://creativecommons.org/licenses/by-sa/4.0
